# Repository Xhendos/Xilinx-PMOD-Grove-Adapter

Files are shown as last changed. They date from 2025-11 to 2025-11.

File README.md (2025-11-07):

# Xilinx-PMOD-Grove-Adapter

I wanted to try [Xilinx PYNQ Workshop](github.com/Xilinx/PYNQ_Workshop) in order to run HLS code on the FPGA fabric of the Zynq 7020 SoC. However, the workshop relies on [Grove](https://wiki.sipeed.com/soft/maixpy/en/modules/grove/index.html)-type sensors. 
There used to be a PMOD to Grove adapter board, but it is not for sale anymore ([original](https://pynq.readthedocs.io/en/v2.5.1/pynq_libraries/grove.html)). That is why I decided to make my own PMOD to Grove adapter board that has been tested and used for the PYNQ-Z2 board, but should work with other boards as well. 

<p align="center">
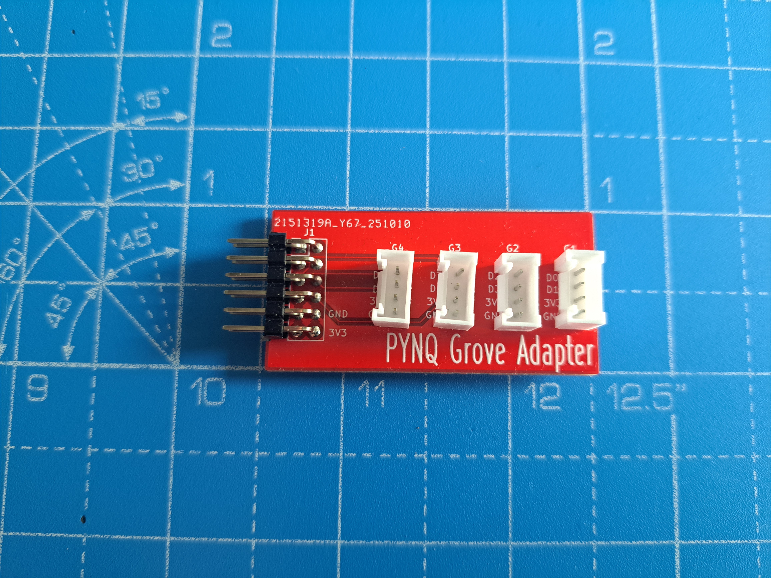
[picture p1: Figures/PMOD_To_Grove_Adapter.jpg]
  
  
</p>

# Bill of Material (BOM)

The most widely available option is AliExpress, that is where I ordered the components. The PCBs are ordered at JLCPCB.

Product  | Link
------------- | -------------
2x6 male pin header (angled) | [link](https://nl.aliexpress.com/item/1005007673111748.html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)
Grove connector  | [link](https://nl.aliexpress.com/item/32814974160.html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)

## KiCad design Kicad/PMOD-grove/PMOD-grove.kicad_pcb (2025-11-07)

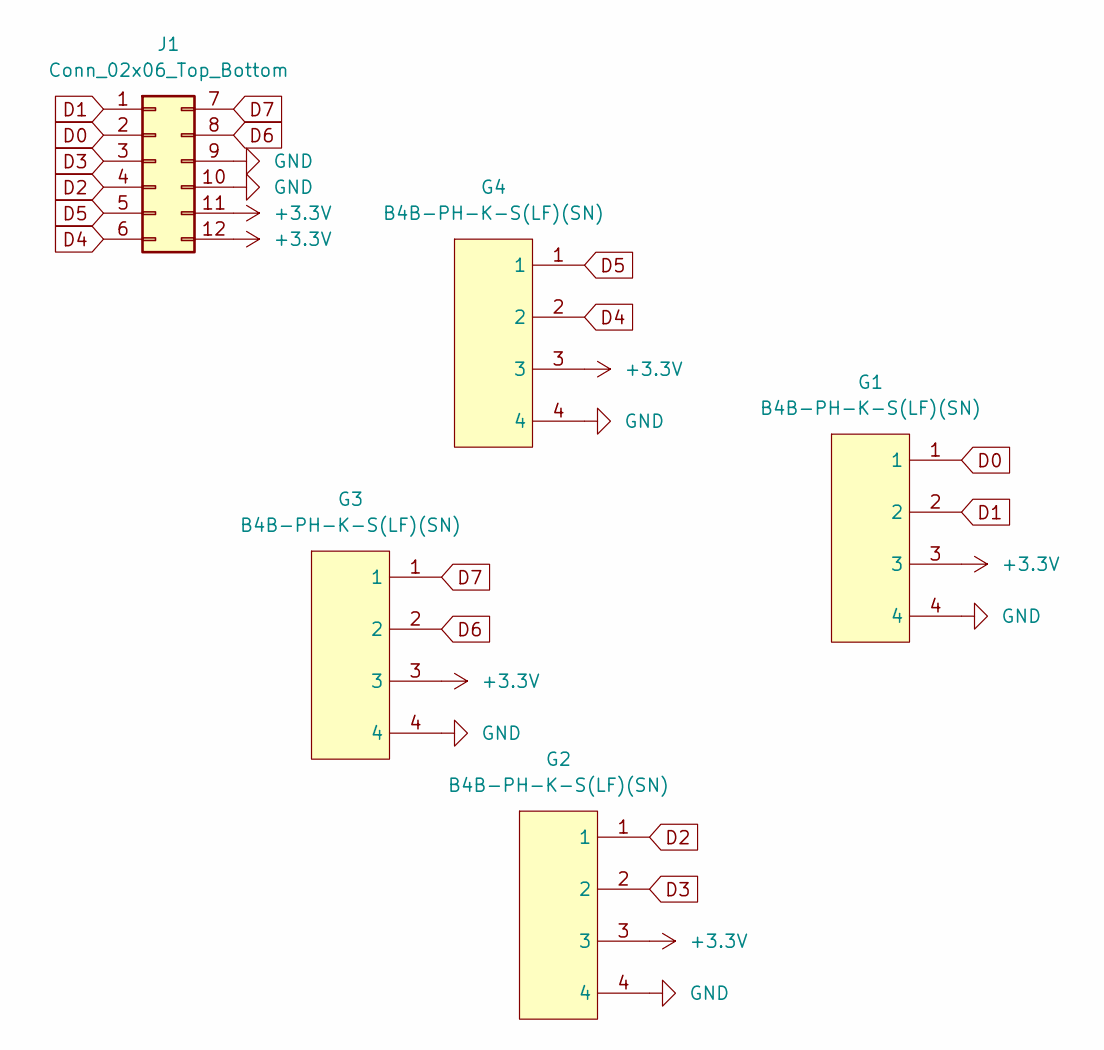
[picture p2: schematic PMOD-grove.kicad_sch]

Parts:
G1, G2, G3, G4: B4B-PH-K-S(LF)(SN); CONN-TH_B4B-PH-K-S; LCSC Part C131334
J1: Conn_02x06_Top_Bottom; PinHeader_2x06_P2.54mm_Vertical

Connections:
+3.3V: G1.3, G2.3, G3.3, G4.3, J1.11, J1.12
D0: G1.1, J1.2
D1: G1.2, J1.1
D2: G2.1, J1.4
D3: G2.2, J1.3
D4: G4.2, J1.6
D5: G4.1, J1.5
D6: G3.2, J1.8
D7: G3.1, J1.7
GND: G1.4, G2.4, G3.4, G4.4, J1.9, J1.10

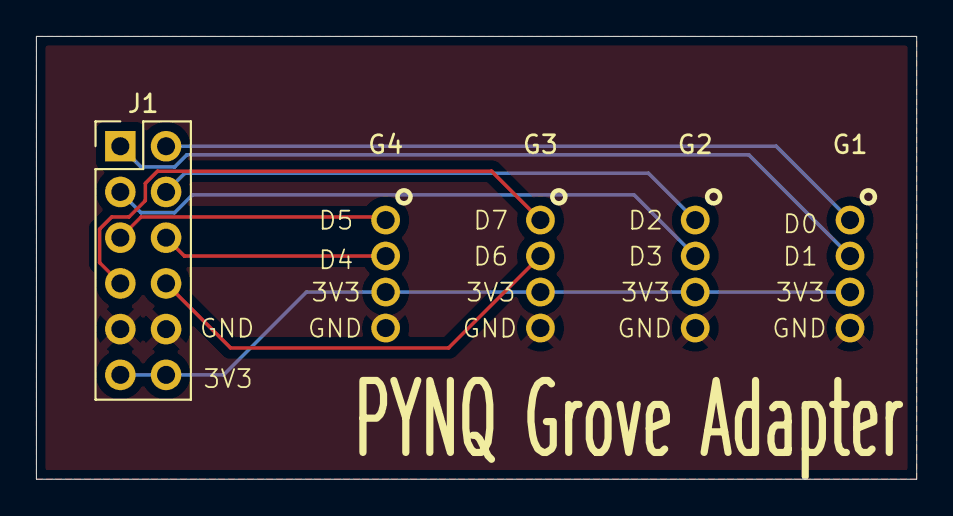
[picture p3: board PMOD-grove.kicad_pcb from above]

Board: 2 copper layers, 48.9 x 24.6 mm, 5 parts (0 on the bottom side), 10 nets.

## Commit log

2025-11-07 Add KiCad project, Gerbers and Figures
    [PMOD-grove.kicad_pcb, PMOD-grove.kicad_sch]
2025-11-07 Added Bill of Material section
